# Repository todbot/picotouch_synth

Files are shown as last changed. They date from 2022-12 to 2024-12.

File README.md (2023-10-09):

# picotouch_synth

Thin captouch-based synth platform for Raspberry Pi Pico

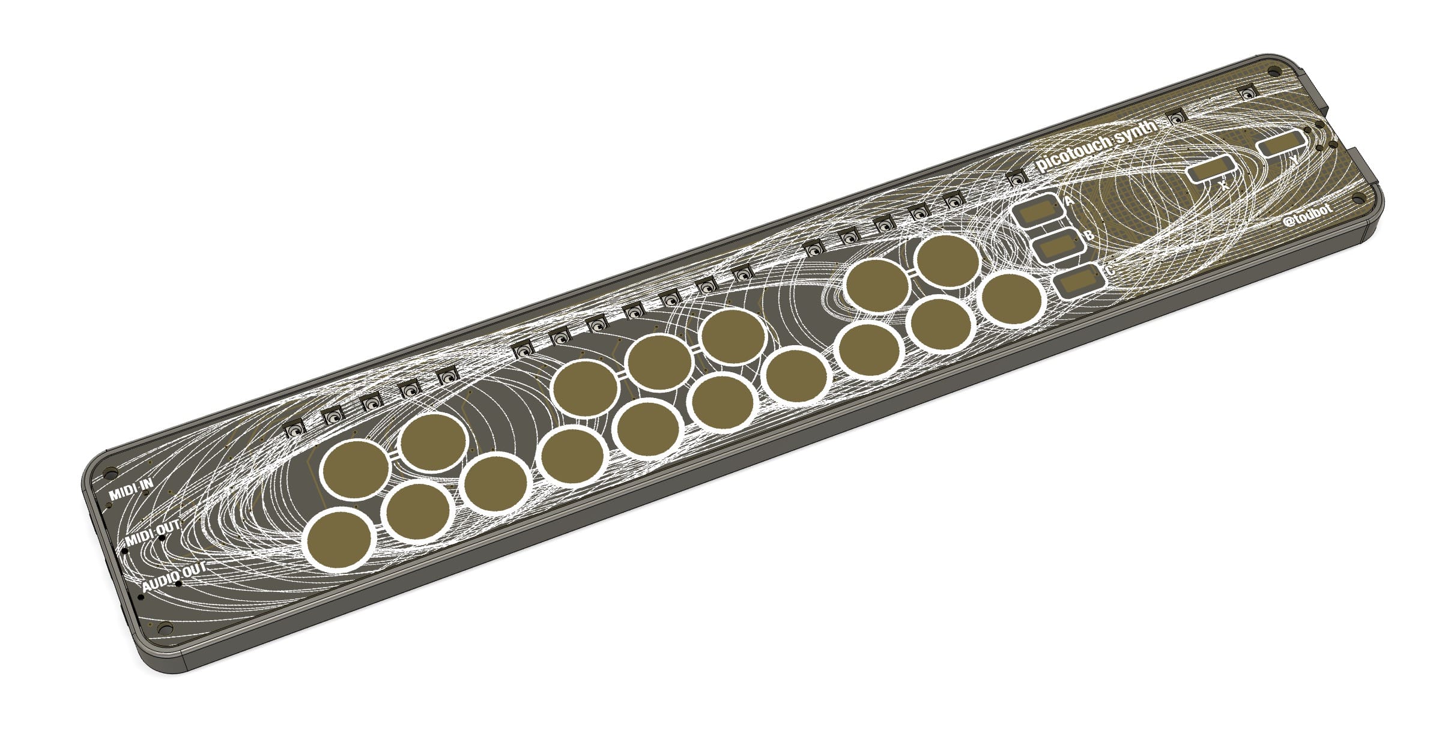
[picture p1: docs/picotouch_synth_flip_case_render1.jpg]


Features:
* Raspberry Pi Pico
* PWM Audio out
* TRS-A MIDI In / Out
* USB MIDI In/Out
* 19 RGB LEDs
* 22 touch pads (17 notes, 5 modifiers)
* Low part count: [14 BOM line items, mostly passives](./schematics/picotouch_synth_flip_bottom_bom.csv)
* Completely flat surface (only reverse-mount LEDs, capsense pads)
* 6 mm thick when in [minimal enclosure](https://github.com/todbot/picotouch_synth/tree/main/enclosure)
   (255 x 42 x 6 mm volume)

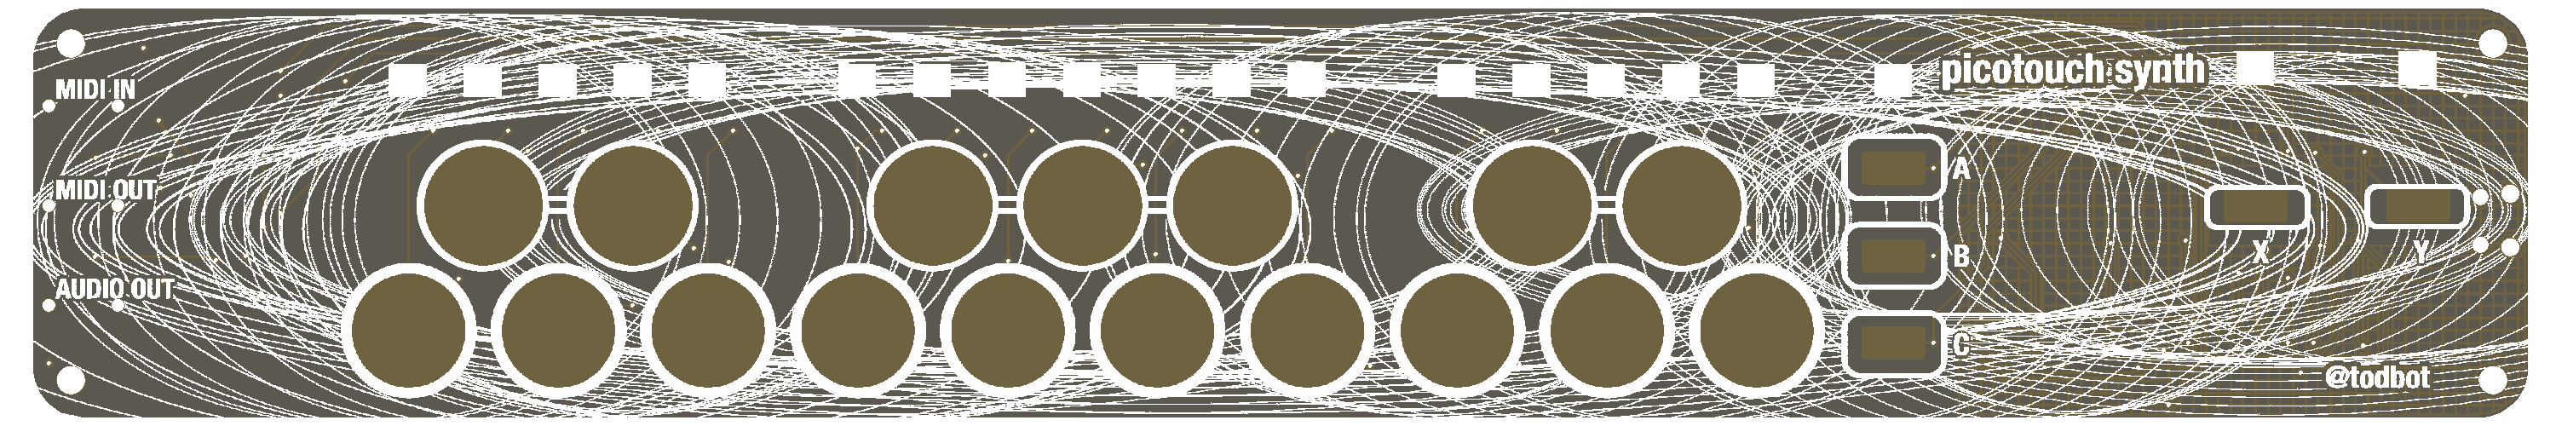
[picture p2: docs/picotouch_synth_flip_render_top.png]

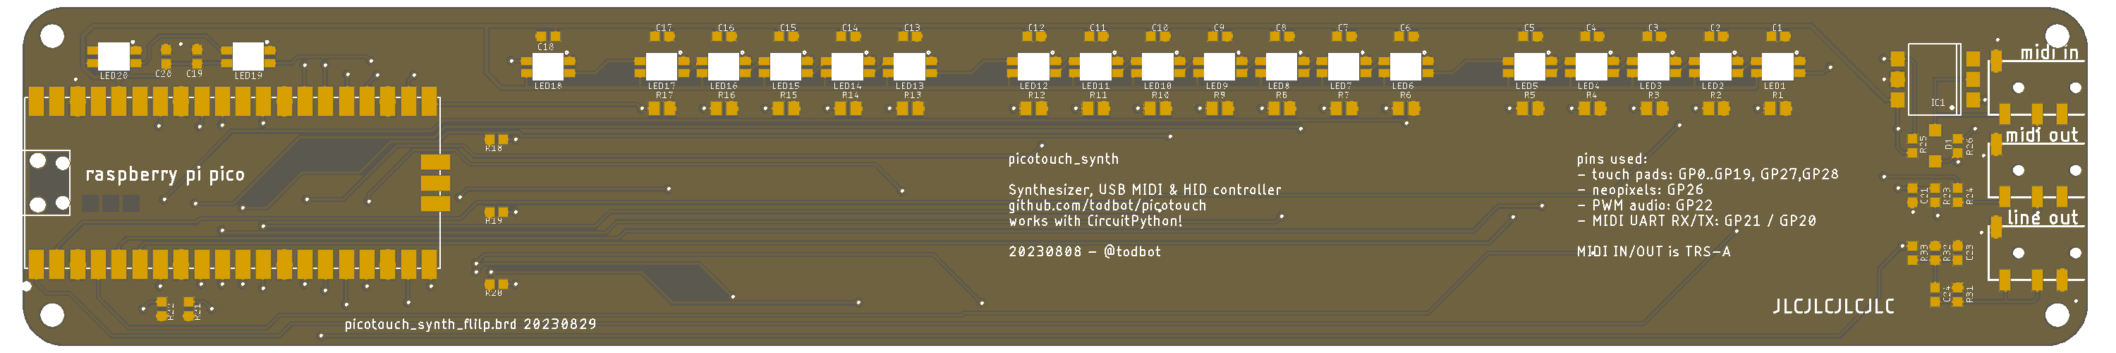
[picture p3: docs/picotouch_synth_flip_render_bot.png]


## Installing firmware

There are currently three "applications" for the picotouch_synth board, all are in active development,
so check the [Release page](https://github.com/todbot/picotouch_synth/releases)
for latest versions as prebuilt UF2 images.

- [picotouch_synth](./circuitpython/picotouch_synth) -- a wavetable synth with three different patches
  ([video demo](https://www.youtube.com/watch?v=0FgqWdkIjWM))
- [pts_drum_machine](./circuitpython/pts_drum_machine) -- a drum sample player
  ([video demo](https://www.youtube.com/watch?v=OaN6xVYXhNE))
- [hwtest](./circuitpython/hwtest/) -- simple hardware test of the board

### Installing prebuilt UF2 images

Instead of installing CircuitPython, then installling needed libraries,
and finally installing the code you want, you can just copy a UF2 file to the RPI-RP2 bootloader drive!

As a rule, all firmware will be offered as pre-built firmware UF2 images for picotouch_synth.
Go to the [Releases](https://github.com/todbot/picotouch_synth/releases) page
and download the UF2 you want.  Then, to install:

* Unplug picotouch_synth PCB board from USB
* Unclip PCB from case ([see this video on releasing the case](https://youtu.be/MjScFP873SQ))
* Hold BOOT button on Pico while plugging back into USB
* Copy the UF2 file to the RPI-RP2 drive
* When board finishes reflashing, it will reboot

__Note:__ if your Pico has more than the 2 MB standard flash
(like the [purple "RetroScaler" 16MB USB-C ones](https://www.aliexpress.us/item/3256804731684211.html)),
the UF2s will still work but the resulting CIRCUITPY drive only be 1 MB.
To get the flash space back, you will need to
[install CircuitPython](https://learn.adafruit.com/welcome-to-circuitpython/installing-circuitpython#for-rp2040-boards-3105171)
and install the code files by hand.

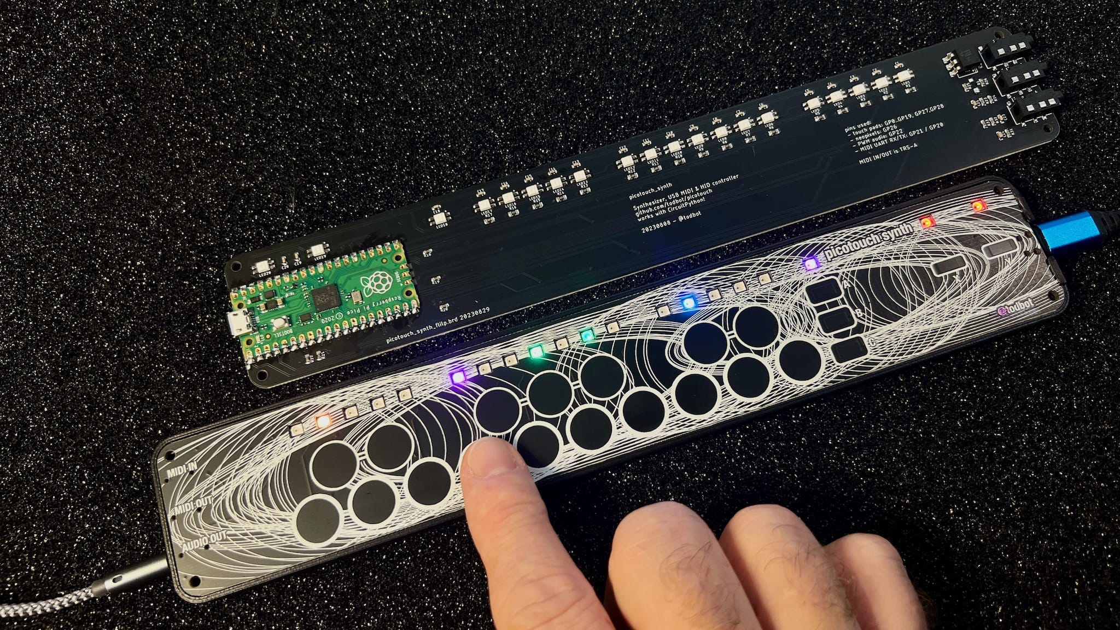
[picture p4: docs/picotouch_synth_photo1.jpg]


## Sketching in Hardware 2023 Edition

For the Sketching in Hardware conference, the firmware shipped on the boards is in
[circuitpython/picotouch_synth](https://github.com/todbot/picotouch_synth/tree/main/circuitpython/picotouch_synth)
and the pre-built UF2 firwmare in the [Releases section](https://github.com/todbot/picotouch_synth/releases/tag/v1).

There were two different boards handed out:
- [micro-USB green Raspberry Pi Picos w/ 2 MB flash](https://www.raspberrypi.com/documentation/microcontrollers/raspberry-pi-pico.html)
- [USB-C purple "RetroScaler" Pico clones w/ 16 MB flash](https://www.aliexpress.us/item/3256804731684211.html).

Both are formated as 2MB devices so if you have a purple board and want the extra flash space,
you'll need to
[install CircuitPython](https://learn.adafruit.com/welcome-to-circuitpython/installing-circuitpython#for-rp2040-boards-3105171)
and the code files by hand.

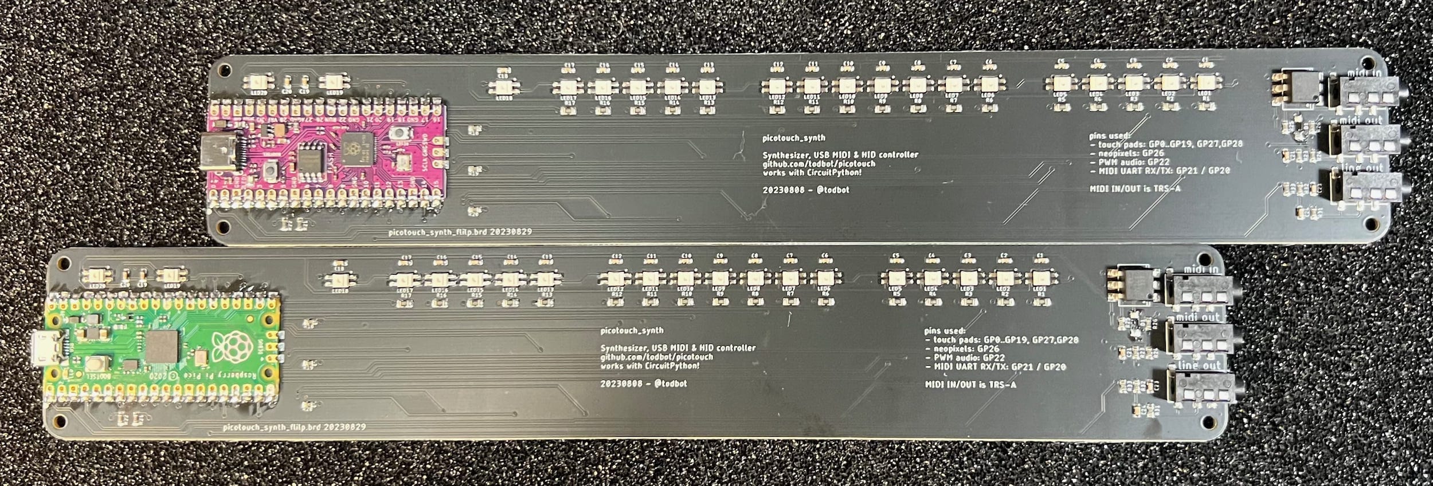
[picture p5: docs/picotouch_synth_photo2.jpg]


### The picotouch_synth application

The keyboard is laid out as top row is modulators (three groups of "sliders")
and the bottom row plays notes in a particular scale.
The A/B/C buttons select different sounds and the X/Y buttons on the right transpose up/down octaves.

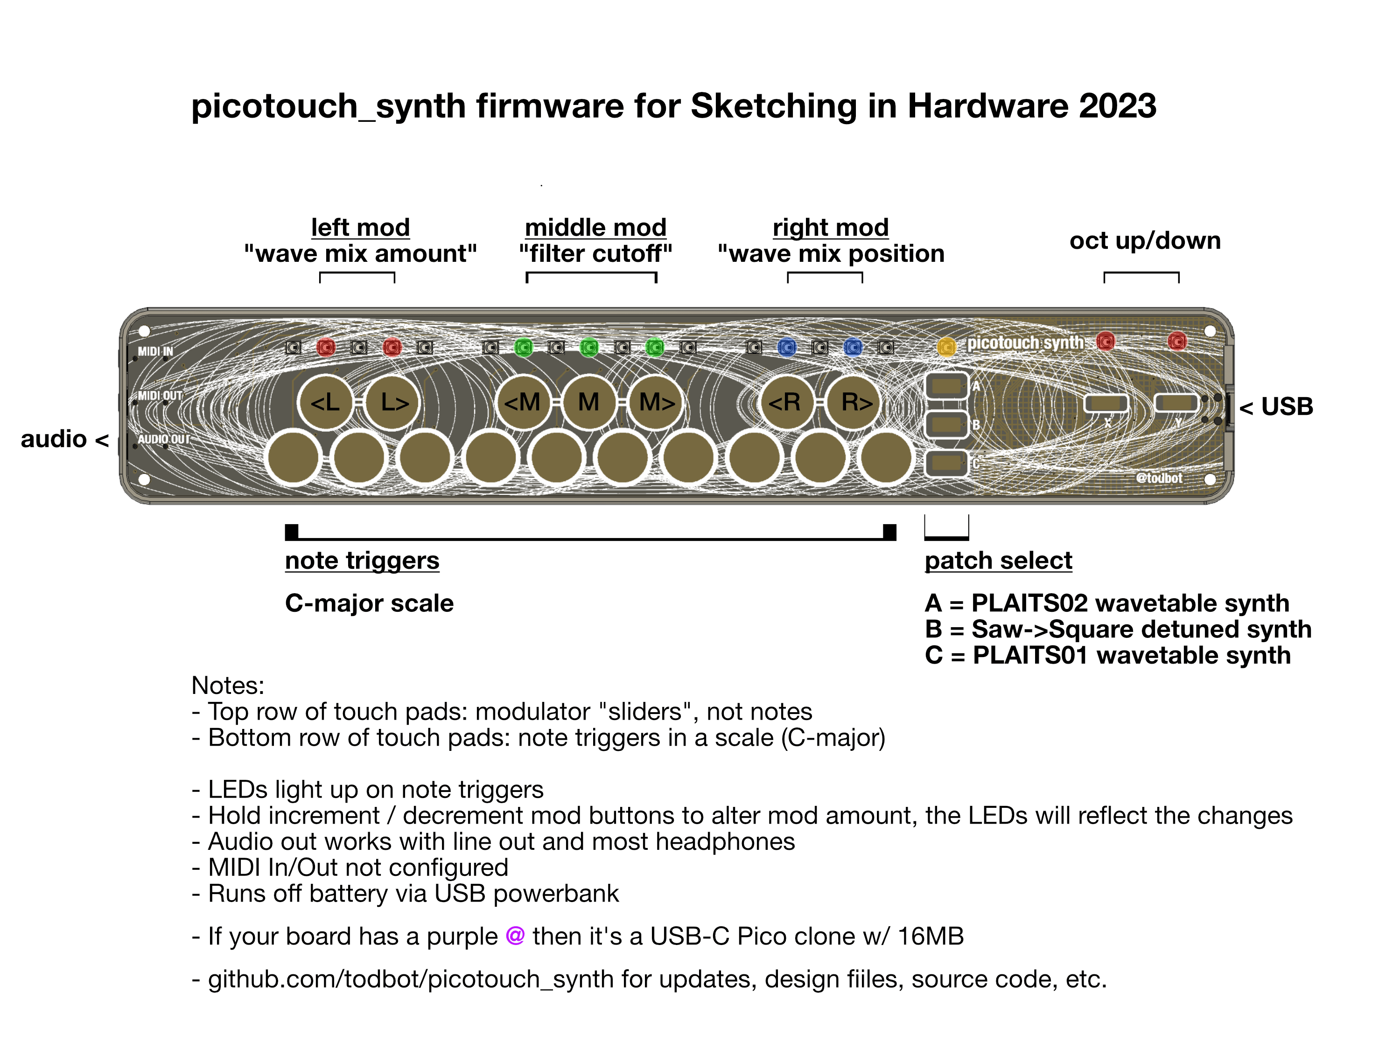
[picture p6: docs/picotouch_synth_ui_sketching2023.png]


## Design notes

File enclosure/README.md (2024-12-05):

The official minimal enclosure is "[picotouch_synth_case.stl](./picotouch_synth_case.stl)".

Fusion 360 CAD file also included.

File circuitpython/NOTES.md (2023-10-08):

# Saving UF2 images for releases

To save full state of Pico, use `picotool`
(available via homebrew on MacOS, build from source on Ubuntu)

Once picotool is installed, put board in BOOT mode by holding BOOTSEL on power up.
Then, save entire state of device into a 4MB UF2 file (twice the 2MB flash on a Pico) with:

```sh
picotool save -a picotouch_synth.uf2
```

Note that if you're using a 16MB Pico clone like the
[purple "RetroScaler" 16MB USB-C ones](https://www.aliexpress.us/item/3256804731684211.html),
the `-a` flag will generate a 32MB UF2 file.

So, to "fool" the RP2040 and CircuitPython into thinking a 16MB flash
(which is slower to write for some reason) is only a 2MB flash (and thus faster to write)
by doing a ranged save:

```sh
picotool save -r 0x10000000 0x10200000  picotouch_synth.uf2
```

This can be uploaded to a 16MB Pico clone and it will now look and act like a 2MB Pico.
The downside is you cannot access the other 14MB of the flash.

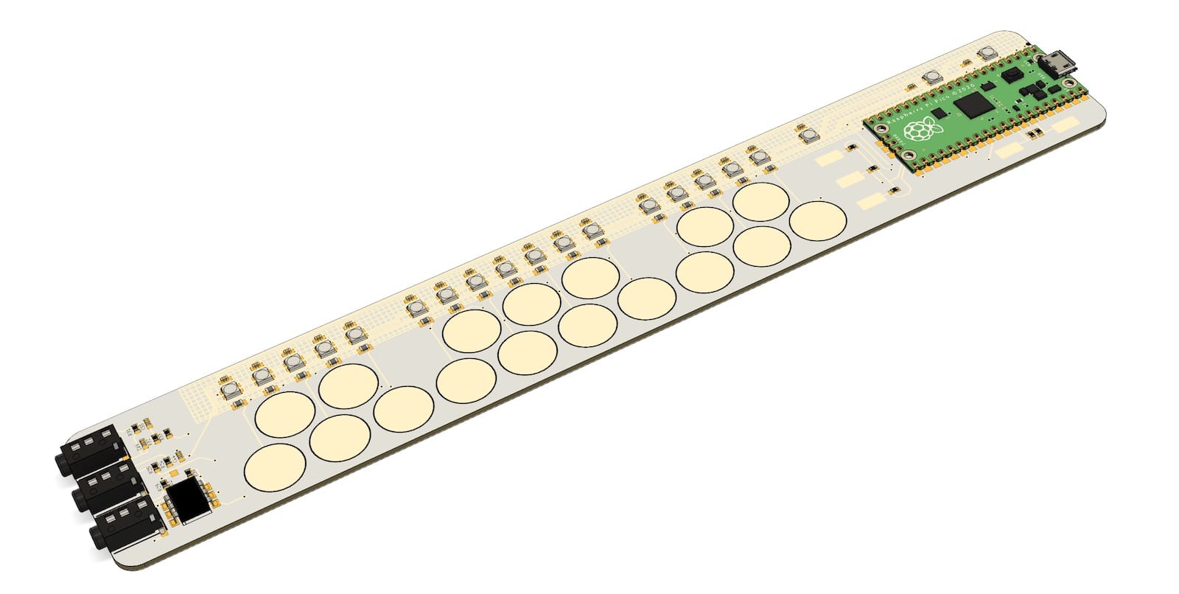
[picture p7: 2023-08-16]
docs/picotouch_synth_render1.jpg

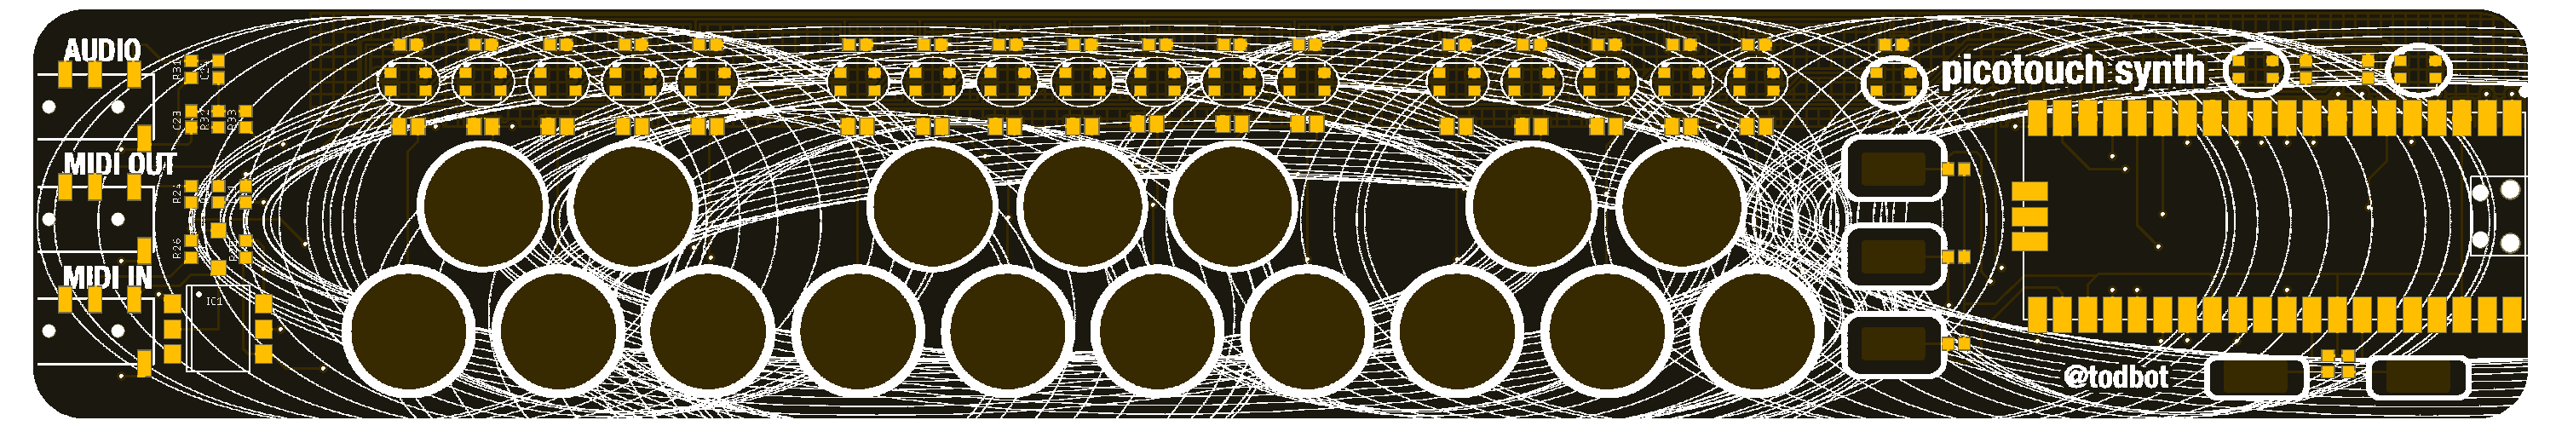
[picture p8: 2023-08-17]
docs/picotouch_synth_toprender_blk.png

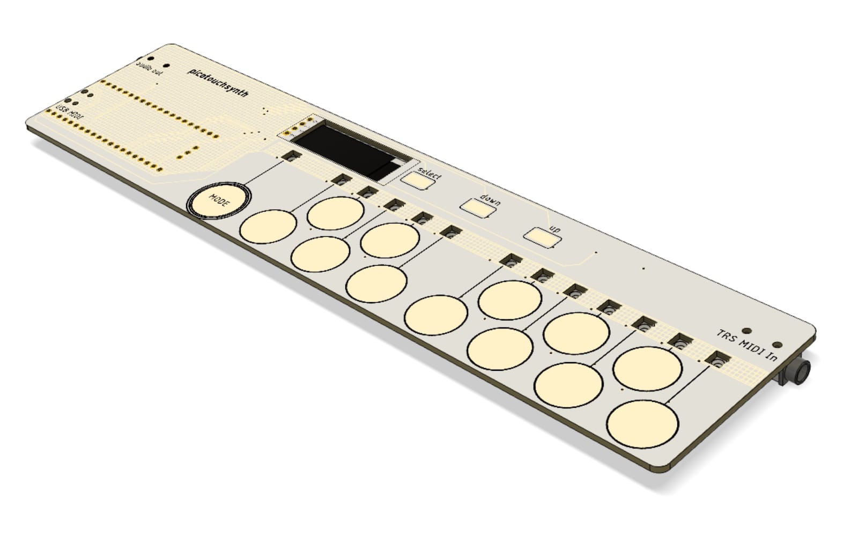
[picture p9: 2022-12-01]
docs/cadshot1.jpg

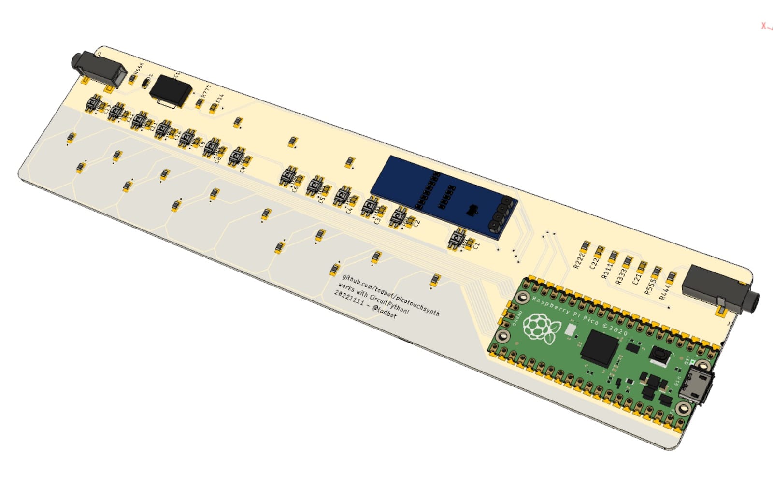
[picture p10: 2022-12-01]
docs/cadshot2.jpg

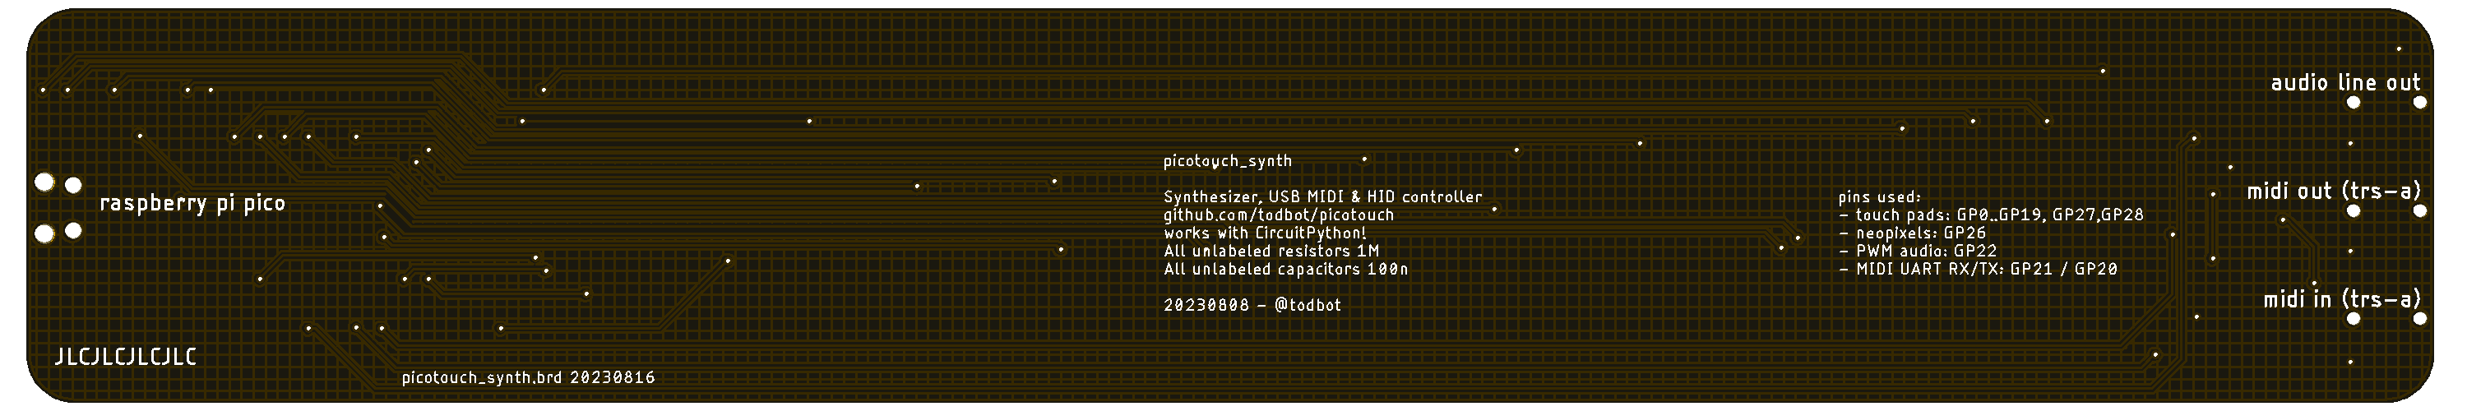
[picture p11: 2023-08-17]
docs/picotouch_synth_botrender_blk.png

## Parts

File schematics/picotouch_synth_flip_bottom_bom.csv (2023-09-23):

Comment | Designator | Footprint | LCSC Part #
1.8k | R31 | R0603
1M | R1 R2 R3 R4 R5 R6 R7 R8 R9 R10 R11 R12 R13 R14 R15 R16 R17 | R0805
1M | R18 R19 R20 R21 R22 | R0603
1N4148 | D1 | SOD123
4.70k | R25 | R0603
10 | R24 | R0603
33 | R23 | R0603
47uF | C24 | C0603
100 | R32 | R0603
100n | C1 C2 C3 C4 C5 C6 C7 C8 C9 C10 C11 C12 C13 C14 C15 C16 C17 C18 C19 C20 C21 C23 | C0603
220 | R26 R33 | R0603
AUDIO-JACK-TRRS | J1 J2 J3 | PJ-320D_SPARKFUN | C431535
H11L1MS | IC1 | DIL6-SMD | C78589
MICROBUILDER_WS2812B_SK6812E | LED1 LED2 LED3 LED4 LED5 LED6 LED7 LED8 LED9 LED10 LED11 LED12 LED13 LED14 LED15 LED16 LED17 LED18 LED19 LED20 | MICROBUILDER_NEO3535_REVERSE
RASPBERRY_PICOSMD | U1 | PICO-PKG-SMD

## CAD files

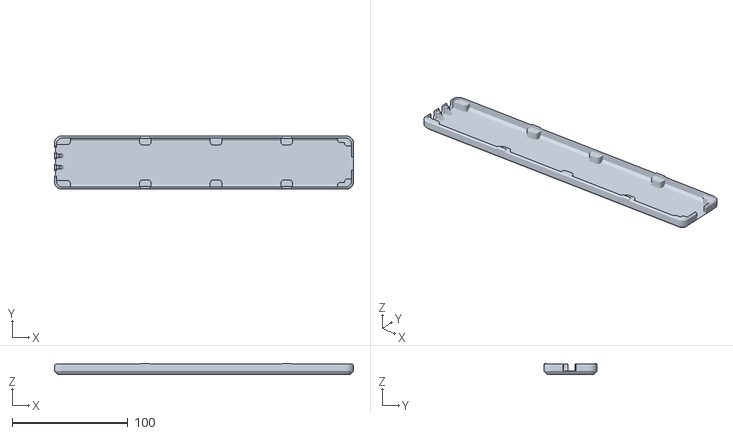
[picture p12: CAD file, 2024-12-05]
enclosure/picotouch_synth_case.stl
257.9 x 45.7 x 9.80

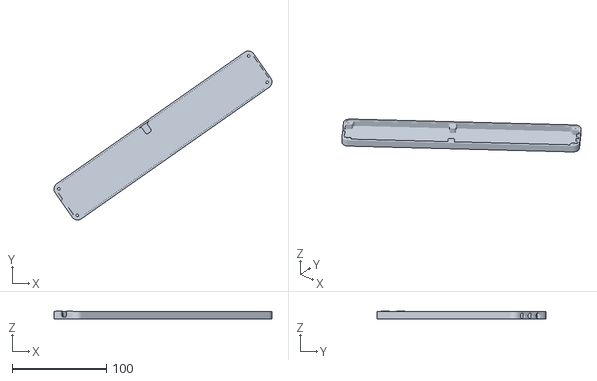
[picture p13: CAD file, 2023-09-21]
enclosure/picotouch_synth_flip_case.stl
231.8 x 179.7 x 8.90

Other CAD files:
enclosure/picotouch_synth_case.f3z
enclosure/picotouch_synth_flip_case.f3z

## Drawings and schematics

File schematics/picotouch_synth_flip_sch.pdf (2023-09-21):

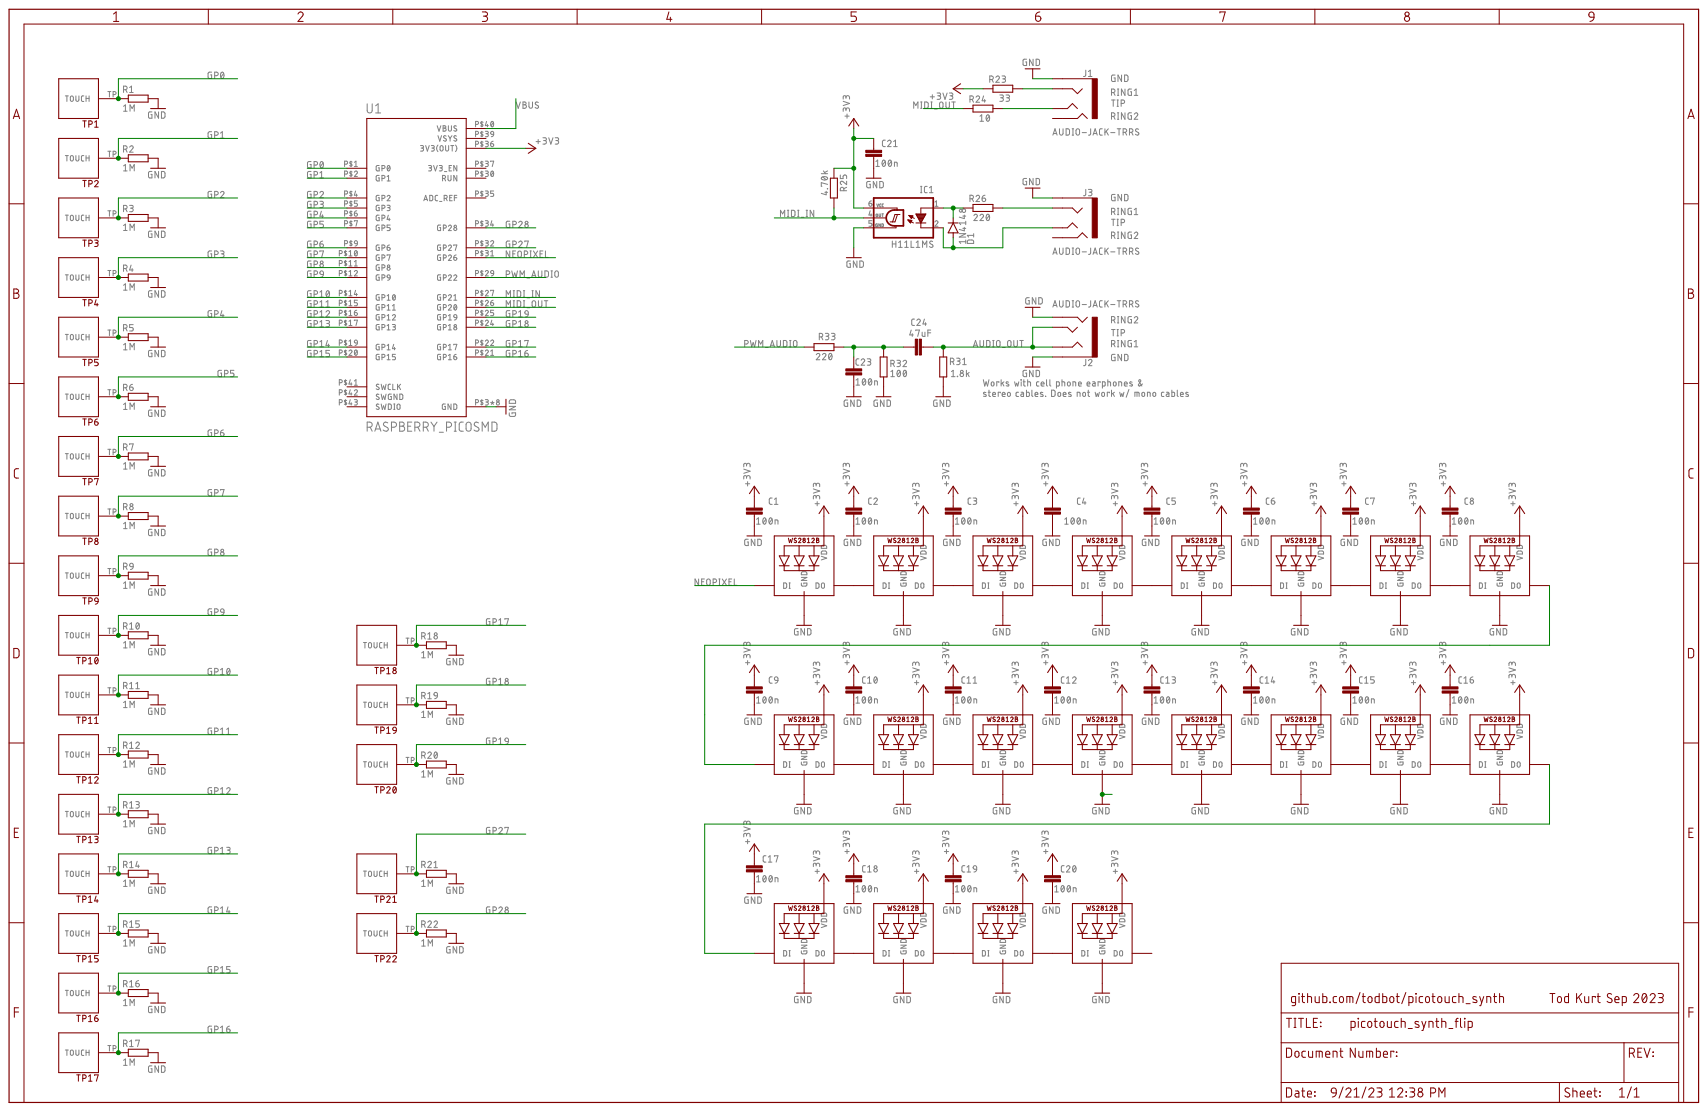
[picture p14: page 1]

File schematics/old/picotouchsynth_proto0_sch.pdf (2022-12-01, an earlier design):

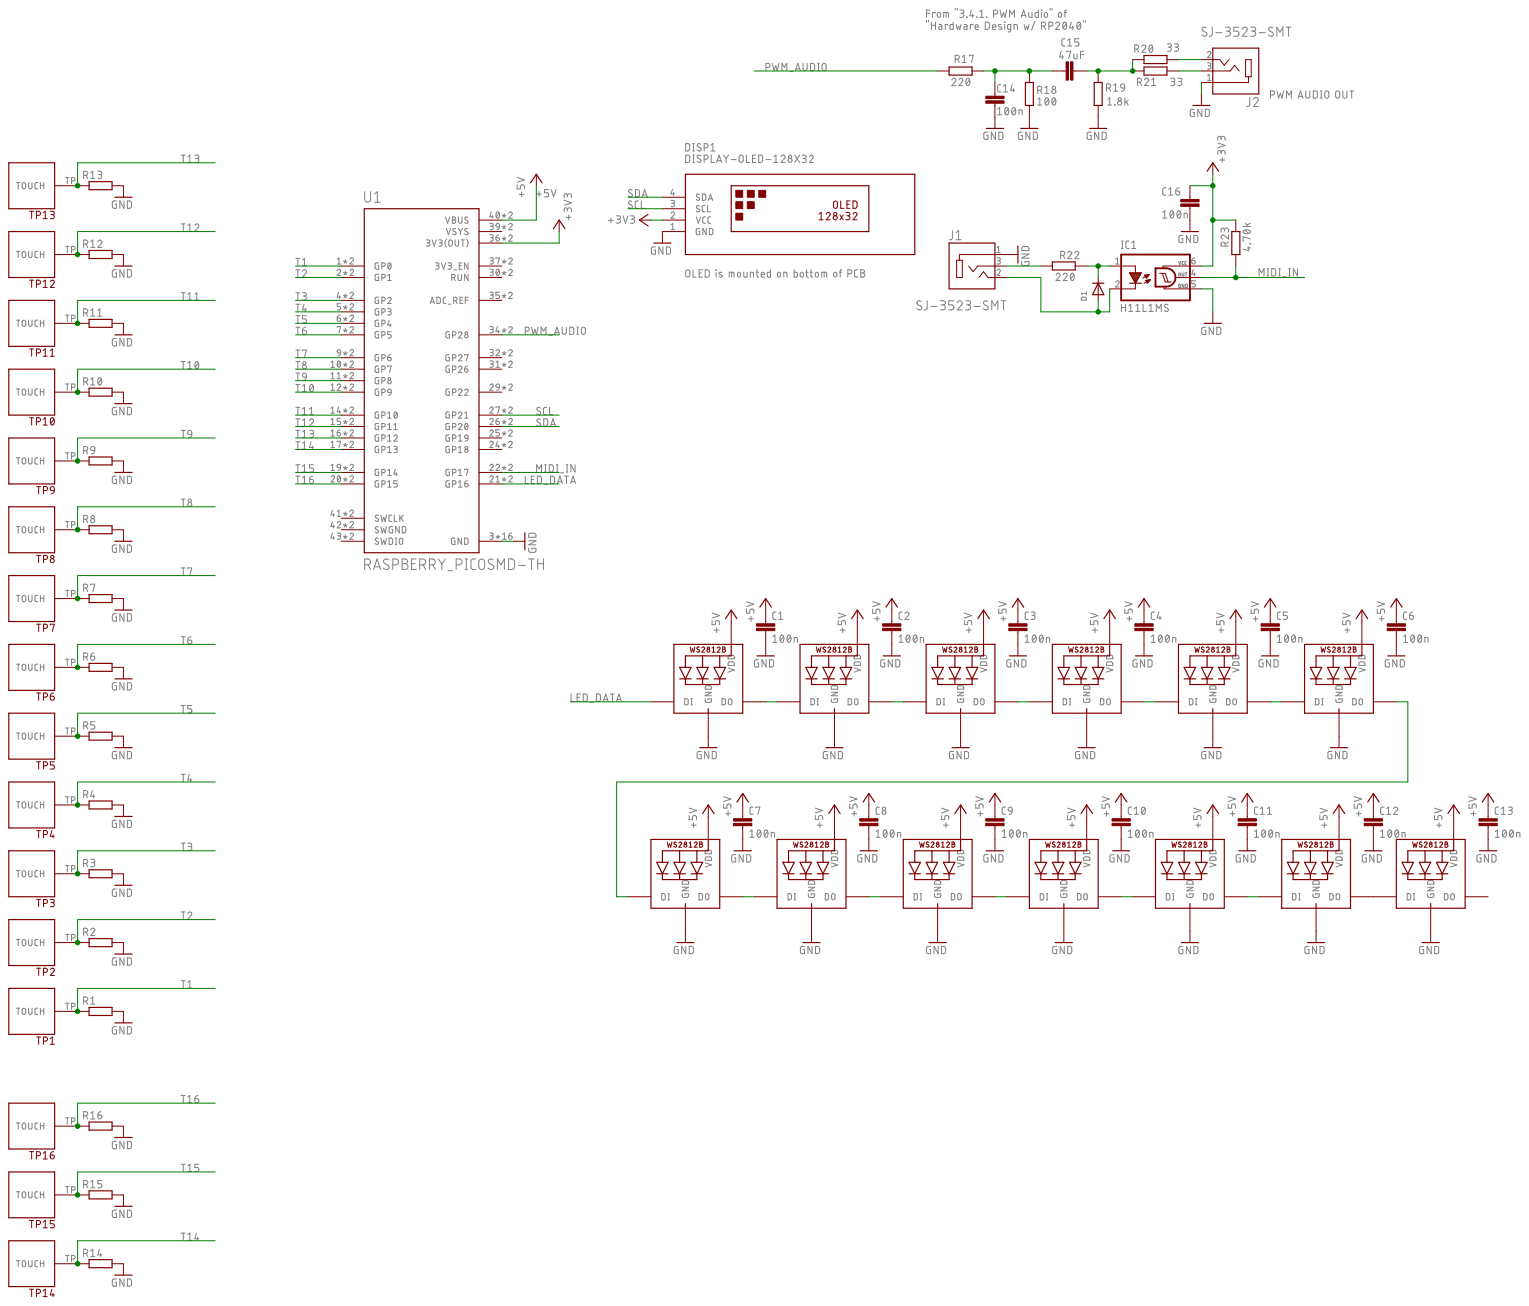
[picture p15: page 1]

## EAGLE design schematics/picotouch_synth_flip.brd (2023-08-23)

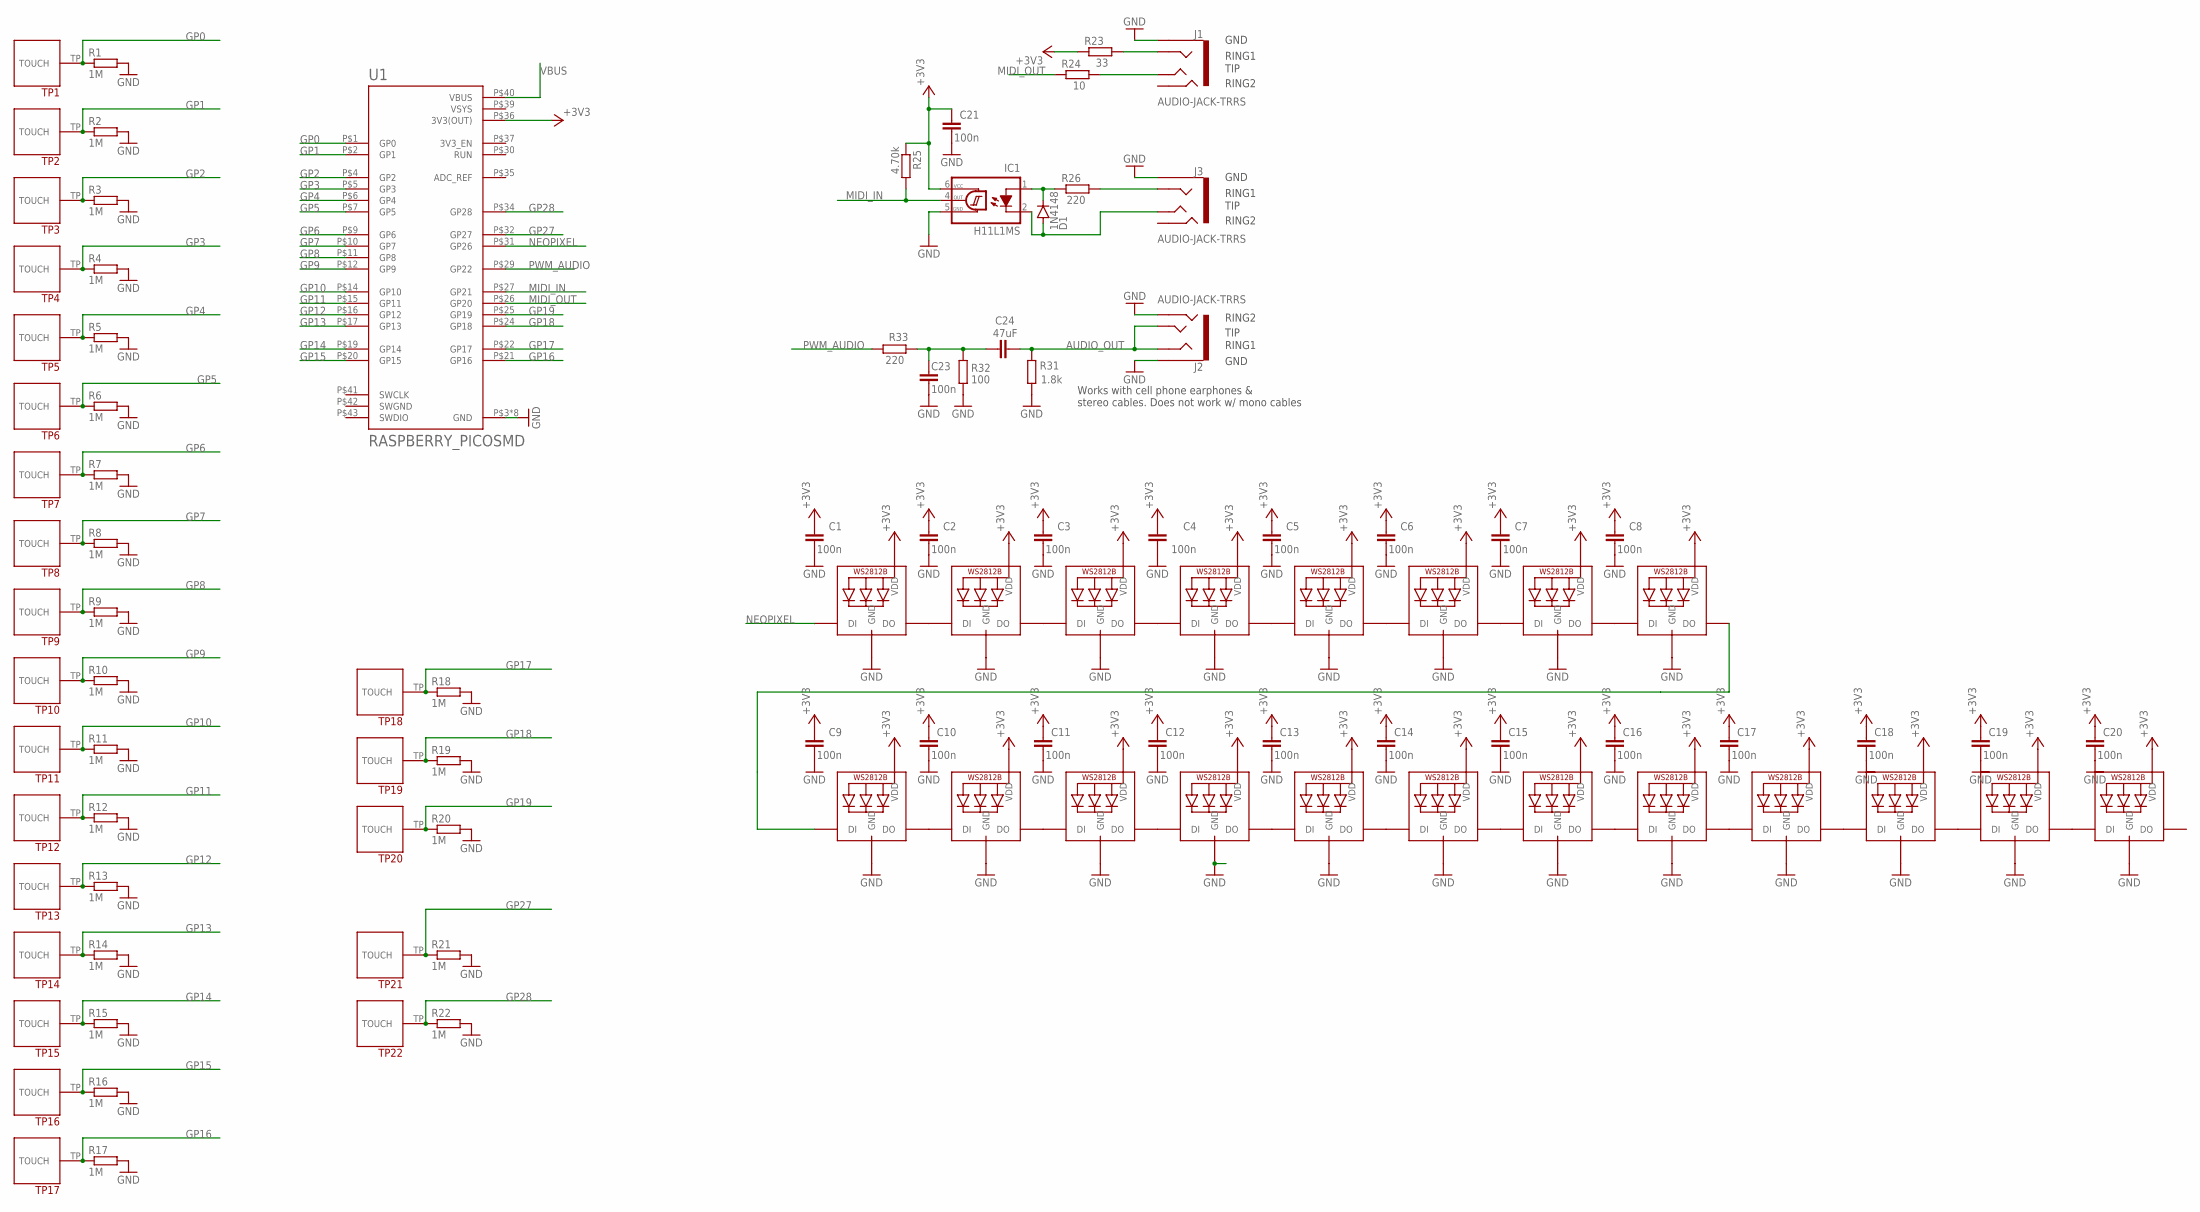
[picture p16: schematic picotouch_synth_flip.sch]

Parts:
C1, C2, C3, C4, C5, C6, C7, C8, C9, C10, C11, C12, C13, C14, C15, C16, C17, C18, C19, C20, C21, C23: 100n; C0603
C24: 47uF; C0603
D1: 1N4148; SOD123
IC1: H11L1MS; DIL6-SMD; MPN2 H11L1S; LCSC C78589
J1, J3: AUDIO-JACK-TRRS; PJ-320D_SPARKFUN
J2: AUDIO-JACK-TRRS; PJ-320D_SPARKFUN; LCSC C431535
LED1, LED2, LED3, LED4, LED5, LED6, LED7, LED8, LED9, LED10, LED11, LED12, LED13, LED14, LED15, LED16, LED17, LED18, LED19, LED20: MICROBUILDER_WS2812B_SK6812E; MICROBUILDER_NEO3535_REVERSE
R1, R2, R3, R4, R5, R6, R7, R8, R9, R10, R11, R12, R13, R14, R15, R16, R17: 1M; R0805
R18, R19, R20, R21, R22: 1M; R0603
R23: 33; R0603
R24: 10; R0603
R25: 4.70k; R0603
R26, R33: 220; R0603
R31: 1.8k; R0603
R32: 100; R0603
TP1, TP2, TP3, TP4, TP5, TP6, TP7, TP8, TP9, TP10, TP11, TP12, TP13, TP14, TP15, TP16, TP17: TOUCHPADA
TP18, TP19, TP20, TP21, TP22: TOUCHPADB
U1: RASPBERRY_PICOSMD; PICO-PKG-SMD

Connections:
+3V3: C1.1, C2.1, C3.1, C4.1, C5.1, C6.1, C7.1, C8.1, C9.1, C10.1, C11.1, C12.1, C13.1, C14.1, C15.1, C16.1, C17.1, C18.1, C19.1, C20.1, C21.1, IC1.6 (VCC), LED1.1-VDD (VDD), LED2.1-VDD (VDD), LED3.1-VDD (VDD), LED4.1-VDD (VDD), LED5.1-VDD (VDD), LED6.1-VDD (VDD), LED7.1-VDD (VDD), LED8.1-VDD (VDD), LED9.1-VDD (VDD), LED10.1-VDD (VDD), LED11.1-VDD (VDD), LED12.1-VDD (VDD), LED13.1-VDD (VDD), LED14.1-VDD (VDD), LED15.1-VDD (VDD), LED16.1-VDD (VDD), LED17.1-VDD (VDD), LED18.1-VDD (VDD), LED19.1-VDD (VDD), LED20.1-VDD (VDD), R23.1, R25.1, U1.P$36 (3V3(OUT))
AUDIO_OUT: C24.2, J2.RING1, J2.TIP, R31.1
GND: C1.2, C2.2, C3.2, C4.2, C5.2, C6.2, C7.2, C8.2, C9.2, C10.2, C11.2, C12.2, C13.2, C14.2, C15.2, C16.2, C17.2, C18.2, C19.2, C20.2, C21.2, C23.2, IC1.5 (GND), J1.EARTH, J2.EARTH, J2.RING2, J3.EARTH, LED1.3-GND (GND), LED2.3-GND (GND), LED3.3-GND (GND), LED4.3-GND (GND), LED5.3-GND (GND), LED6.3-GND (GND), LED7.3-GND (GND), LED8.3-GND (GND), LED9.3-GND (GND), LED10.3-GND (GND), LED11.3-GND (GND), LED12.3-GND (GND), LED13.3-GND (GND), LED14.3-GND (GND), LED15.3-GND (GND), LED16.3-GND (GND), LED17.3-GND (GND), LED18.3-GND (GND), LED19.3-GND (GND), LED20.3-GND (GND), R1.2, R2.2, R3.2, R4.2, R5.2, R6.2, R7.2, R8.2, R9.2, R10.2, R11.2, R12.2, R13.2, R14.2, R15.2, R16.2, R17.2, R18.2, R19.2, R20.2, R21.2, R22.2, R31.2, R32.1, U1.P$3 (GND), U1.P$8 (GND), U1.P$13 (GND), U1.P$18 (GND), U1.P$23 (GND), U1.P$28 (GND), U1.P$33 (GND), U1.P$38 (GND)
GP0: R1.1, TP1.TP, U1.P$1 (GP0)
GP1: R2.1, TP2.TP, U1.P$2 (GP1)
GP2: R3.1, TP3.TP, U1.P$4 (GP2)
GP3: R4.1, TP4.TP, U1.P$5 (GP3)
GP4: R5.1, TP5.TP, U1.P$6 (GP4)
GP5: R6.1, TP6.TP, U1.P$7 (GP5)
GP6: R7.1, TP7.TP, U1.P$9 (GP6)
GP7: R8.1, TP8.TP, U1.P$10 (GP7)
GP8: R9.1, TP9.TP, U1.P$11 (GP8)
GP9: R10.1, TP10.TP, U1.P$12 (GP9)
GP10: R11.1, TP11.TP, U1.P$14 (GP10)
GP11: R12.1, TP12.TP, U1.P$15 (GP11)
GP12: R13.1, TP13.TP, U1.P$16 (GP12)
GP13: R14.1, TP14.TP, U1.P$17 (GP13)
GP14: R15.1, TP15.TP, U1.P$19 (GP14)
GP15: R16.1, TP16.TP, U1.P$20 (GP15)
GP16: R17.1, TP17.TP, U1.P$21 (GP16)
GP17: R18.1, TP18.TP, U1.P$22 (GP17)
GP18: R19.1, TP19.TP, U1.P$24 (GP18)
GP19: R20.1, TP20.TP, U1.P$25 (GP19)
GP27: R21.1, TP21.TP, U1.P$32 (GP27)
GP28: R22.1, TP22.TP, U1.P$34 (GP28)
MIDI_IN: IC1.4 (OUT), R25.2, U1.P$27 (GP21)
MIDI_OUT: R24.1, U1.P$26 (GP20)
unnamed: D1.C, IC1.1 (A), R26.1
unnamed: J1.TIP, R24.2
unnamed: D1.A, IC1.2 (C), J3.TIP
unnamed: J3.RING1, R26.2
unnamed: C23.1, C24.1, R32.2, R33.1
unnamed: J1.RING1, R23.2
unnamed: LED1.2-DOUT (DO), LED2.4-DIN (DI)
unnamed: LED2.2-DOUT (DO), LED3.4-DIN (DI)
unnamed: LED4.2-DOUT (DO), LED5.4-DIN (DI)
unnamed: LED5.2-DOUT (DO), LED6.4-DIN (DI)
unnamed: LED6.2-DOUT (DO), LED7.4-DIN (DI)
unnamed: LED7.2-DOUT (DO), LED8.4-DIN (DI)
unnamed: LED9.2-DOUT (DO), LED10.4-DIN (DI)
unnamed: LED10.2-DOUT (DO), LED11.4-DIN (DI)
unnamed: LED12.2-DOUT (DO), LED13.4-DIN (DI)
unnamed: LED13.2-DOUT (DO), LED14.4-DIN (DI)
unnamed: LED14.2-DOUT (DO), LED15.4-DIN (DI)
unnamed: LED15.2-DOUT (DO), LED16.4-DIN (DI)
unnamed: LED3.2-DOUT (DO), LED4.4-DIN (DI)
unnamed: LED11.2-DOUT (DO), LED12.4-DIN (DI)
unnamed: LED8.2-DOUT (DO), LED9.4-DIN (DI)
unnamed: LED16.2-DOUT (DO), LED17.4-DIN (DI)
unnamed: LED17.2-DOUT (DO), LED18.4-DIN (DI)
unnamed: LED18.2-DOUT (DO), LED19.4-DIN (DI)
unnamed: LED19.2-DOUT (DO), LED20.4-DIN (DI)
NEOPIXEL: LED1.4-DIN (DI), U1.P$31 (GP26)
PWM_AUDIO: R33.2, U1.P$29 (GP22)
SWGND: U1.P$42 (SWGND)
VBUS: U1.P$40 (VBUS)
VSYS: U1.P$39 (VSYS)

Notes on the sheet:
RING2
RING1
GND
TIP
Works with cell phone earphones & stereo cables. Does not work w/ mono cables

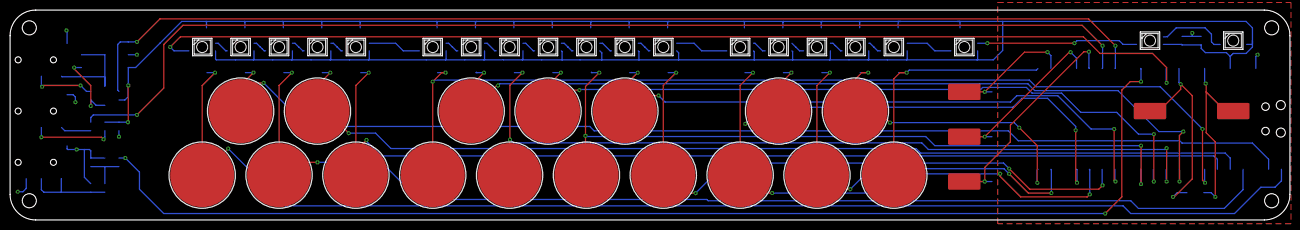
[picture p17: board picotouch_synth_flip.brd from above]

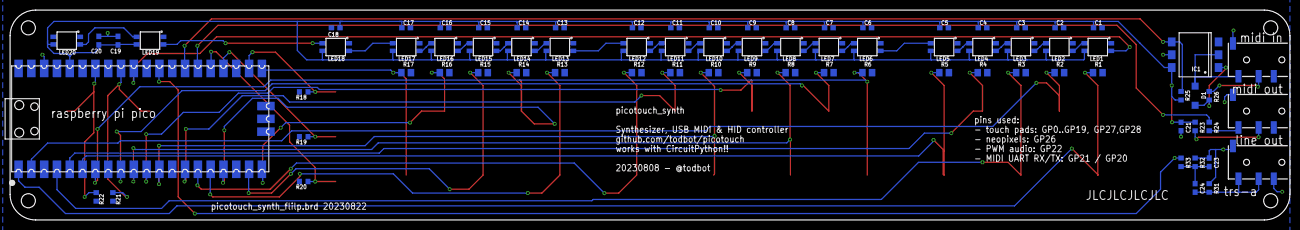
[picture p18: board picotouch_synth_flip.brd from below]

Board: 2 copper layers, 253.8 x 41.6 mm, 100 parts (58 on the bottom side), 54 nets.

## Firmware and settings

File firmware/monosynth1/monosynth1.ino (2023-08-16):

/**
 * monosynth1.ino - picotouchsynth wubwubwub synth using LowPassFilter
 * based MozziScout "mozziscout_monosynth1"
 *
 * Responds to USB MIDI too
 *
 * Libraries needed:
 * - "arduino-pico" core for Pico - https://arduino-pico.readthedocs.io/en/latest/
 * - Adafruit_TinyUSB - also select in IDE "Tools / USB Stack: Adafruit TinyUSB"
 * - Adafruit_NeoPixel
 * - Adafruit_SSD1306
 * - Mozzi - https://github.com/sensorium/Mozzi - and change Mozzi/AudioConfigRP2040.h to "AUDIO_CHANNEL_1_PIN 28"
 *
 * @todbot 1 Dec 2022
 *
 **/


// Mozzi's controller update rate, seems to have issues at 1024
// If slower than 512 can't get all MIDI from Live
#define CONTROL_RATE 512
// set DEBUG_MIDI 1 to show CCs received in Serial Monitor
#define DEBUG_MIDI_NOTE 1
#define DEBUG_MIDI_CC 1

#include <MozziGuts.h>
#include <Oscil.h>
#include <tables/triangle_analogue512_int8.h>
#include <tables/square_analogue512_int8.h>
#include <tables/saw_analogue512_int8.h>
#include <tables/cos2048_int8.h> // for filter modulation
#include <LowPassFilter.h>
#include <ADSR.h>
#include <Portamento.h>
#include <mozzi_midi.h> // for mtof()
#include <AudioDelayFeedback.h>

#include <Adafruit_TinyUSB.h>
#include <MIDI.h>
#include <Adafruit_NeoPixel.h>
#include <Wire.h>
#include <Adafruit_SSD1306.h>

#include "TouchyTouch.h"

// SETTINGS
//int portamento_time = 50;  // milliseconds
//int env_release_time = 1000; // milliseconds
byte sound_mode = 0; // patch number / program change
bool retrig_lfo = true;
int midi_base_note = 48;  // for touch keyboard
uint8_t led_fade_amount = 2;
float led_brightness = 0.15;

enum KnownCCs {
  Modulation=0,
  Resonance,
  FilterCutoff,
  PortamentoTime,
  EnvReleaseTime,
  CC_COUNT
};

// mapping of KnownCCs to MIDI CC numbers (this is somewhat standardized)
uint8_t midi_ccs[] = {
  1,   // modulation
  71,  // resonance
  74,  // filter cutoff
  5,   // portamento time
  72,  // env release time
};
uint8_t mod_vals[ CC_COUNT ];

Q16n16 deltime; // audio delay

// pinout of how picotouchsynth board is set up
const int num_touch = 16;
const int num_leds = 13;
const int display_w = 128;
const int display_h = 32;
const int touch_pins[] = { 0,1,2,3,4,5,6,7,8,9,10,11,12,13,14,15 };
const int led_pin      = 16;
const int midi_pin     = 17;
const int disp_sda_pin = 20;
const int disp_scl_pin = 21;
const int audio_pin    = 28; // edit Mozzi/AudioConfigRP2040.h to set this
// button indexes
const int BUTTON_MODE   = 0;
const int BUTTON_SELECT = 15;
const int BUTTON_UP     = 14;
const int BUTTON_DOWN   = 13;

Adafruit_USBD_MIDI usb_midi;
MIDI_CREATE_INSTANCE(Adafruit_USBD_MIDI, usb_midi, MIDIusb);

TouchyTouch touches[num_touch];
Adafruit_NeoPixel leds = Adafruit_NeoPixel(num_leds, led_pin, NEO_GRB + NEO_KHZ800);
Adafruit_SSD1306 display(128, 32, &Wire, -1); // -1 = no OLED_RESET

bool keys_pressed[12]; // one per note
int key_mode = 0;

// Oscillators
Oscil<SAW_ANALOGUE512_NUM_CELLS, AUDIO_RATE> aOsc1(SAW_ANALOGUE512_DATA);
Oscil<SAW_ANALOGUE512_NUM_CELLS, AUDIO_RATE> aOsc2(SAW_ANALOGUE512_DATA);
// Filter LFO
Oscil<COS2048_NUM_CELLS, CONTROL_RATE> kFilterMod(COS2048_DATA); // filter mod
// Amplitude envelope
//ADSR <CONTROL_RATE, AUDIO_RATE> envelope;
ADSR <CONTROL_RATE, CONTROL_RATE> envelope;

Portamento <CONTROL_RATE> portamento;
LowPassFilter lpf;

AudioDelayFeedback <128> aDel;


///////////////////////////////////////////////////////////////////////////////
// core1 is for UI and MIDI
//

// fade a color by an amount
uint32_t fadeToBlackBy(uint32_t c, uint8_t amount)
{
  uint8_t r = (uint8_t)(c >> 16);
  uint8_t g = (uint8_t)(c >>  8);
  uint8_t b = (uint8_t)c;
  // fade to black by n
  r = (r>amount) ? r - amount : 0;
  g = (g>amount) ? g - amount : 0;
  b = (b>amount) ? b - amount : 0;
  return (r << 16) | (g << 8) | b;
}

void setup1() {
  Serial.begin(115200);
  MIDIusb.begin(MIDI_CHANNEL_OMNI);   // Initiate MIDI communications, listen to all channels
  MIDIusb.turnThruOff();    // turn off echo

  // LEDs
  leds.begin();
  leds.setBrightness( led_brightness * 255 ); // 51 = 0.2
  leds.show(); // off
  /* for( int i=0; i < num_leds; i++ ) { */
  /*   uint32_t newcolor = leds.ColorHSV(i*255*20); */
  /*   leds.setPixelColor(i, newcolor); */
  /* } */
  /* leds.show(); */

  // Touch buttons
  for(int i=0; i<num_touch; i++) {
    //touches[i] = TouchyTouch();
    touches[i].begin( touch_pins[i] );
    touches[i].threshold += 200; // make a bit more noise-proof
  }

  // Display
  Wire.setSDA(disp_sda_pin);
  Wire.setSCL(disp_scl_pin);
  if(!display.begin(SSD1306_SWITCHCAPVCC, 0x3C)) { // Address 0x3D for 128x64
    Serial.println(F("SSD1306 allocation failed"));
    for(;;); // Don't proceed, loop forever
  }
  display.clearDisplay();
  display.setTextSize(2);
  display.setTextColor(WHITE);
  display.setCursor(10,0);
  display.write("pico");
  display.setCursor(60,0);
  display.write("touch");
  display.setCursor(34,17);
  display.write("synth");
  display.display();

  delay(500);

  display.dim(true);

}


void loop1() {
  handleMIDI();

  // LED fading fade all released note LEDS by same amount
  for ( int i = 0; i < 12; i++) {
    int ledi = i+1;
    uint32_t c = leds.getPixelColor(ledi);
    if( keys_pressed[i] ) {
      c = leds.ColorHSV(millis()*10, 255,255);
      //c = leds.ColorHSV(1000, 255,255);
    }
    c = fadeToBlackBy(c, led_fade_amount);
    leds.setPixelColor(ledi, c);
  }
  leds.show();

  // key handling
  for( int i=0; i<num_touch; i++) {
    touches[i].update();
    //Serial.printf("touch %d %d %d\n", i, touches[i].threshold, touches[i].raw_val_last);

    if( touches[i].rose() ) {
      Serial.printf("pressed %d\n", i);
      if( i==0 ) { // mode button
        key_mode = (key_mode + 1) % 4;
        leds.setPixelColor( 0, leds.ColorHSV(key_mode * 255 * 20, 255,255) );
        Serial.printf("key_mode:%d\n", key_mode);
      }
      else if( i > 0 && i < 13 ) { // notes
        handleNoteOn(0, midi_base_note + i - 1, 100 );
        //for(i=0;i<12;i++) { Serial.printf("%d ",keys_pressed[i]); }; Serial.println();
      }
      else if( i== 13 ) { // up
        midi_base_note += 12;
      }
      else if( i== 14 ) { // down
        midi_base_note -= 12;
      }
      else if( i== 15 ) { // select
        sound_mode = (sound_mode + 1) % 3;
        handleProgramChange(sound_mode);
      }
    }

    if( touches[i].fell() ) {
      Serial.printf("released %d\n", i);
      if( i==0 ) { // mode button
      }
      else if( i > 0 && i < 13 ) {
        handleNoteOff(0, midi_base_note + i - 1, 100 );
      }
    }
  }

  //display.display();
  delay(1); // rate limit, cand probably remove this
}

int circle_size = 6;
int keycircles_x[12];
int keycircles_y[12];

//
void handleNoteOn([[maybe_unused]] byte channel, byte note, byte velocity) {
  #if DEBUG_MIDI_NOTE
  Serial.printf("noteOn %d %d\n", note, velocity);
  #endif
  digitalWrite(LED_BUILTIN,HIGH);

  portamento.start(note);
  envelope.noteOn();

  // display
  int n = note%12;
  keys_pressed[n] = true;
  keycircles_x[n] = random(display_w);;
  keycircles_y[n] = random(display_h);;
  //display.fillCircle(keycircles_x[n], keycircles_y[n], circle_size, INVERSE);
}

//
void handleNoteOff([[maybe_unused]] byte channel, byte note, byte velocity) {
  #if DEBUG_MIDI_NOTE
  Serial.printf("noteOff %d %d\n", note, velocity);
  #endif
  digitalWrite(LED_BUILTIN,LOW);

  envelope.noteOff();

  // display
  int n = note%12;
  keys_pressed[n] = false;
  //display.fillCircle(keycircles_x[n], keycircles_y[n], circle_size, INVERSE);
}

//
void handleControlChange([[maybe_unused]] byte channel, byte cc_num, byte cc_val) {
  #if DEBUG_MIDI_CC
  Serial.printf("CC %d %d\n", cc_num, cc_val);
  #endif
  for( int i=0; i<CC_COUNT; i++) {
    if( midi_ccs[i] == cc_num ) { // we got one
      mod_vals[i] = cc_val;
      // special cases, not set every updateControl()
      if( i == PortamentoTime ) {
        portamento.setTime( mod_vals[PortamentoTime] * 2);
      }
      else if( i == EnvReleaseTime ) {
        Serial.printf("release time: %d\n", mod_vals[EnvReleaseTime]*10);
        envelope.setReleaseTime( mod_vals[EnvReleaseTime]*10 );
      }
    }
  }
}

//
void handleProgramChange(byte m) {
  Serial.print("program change:"); Serial.println((byte)m);
  sound_mode = m;
  if( sound_mode == 0 ) {
    aOsc1.setTable(SAW_ANALOGUE512_DATA);
    aOsc2.setTable(SAW_ANALOGUE512_DATA);

    mod_vals[Modulation] = 0;   // FIXME: modulation unused currently
    mod_vals[Resonance] = 93;
    mod_vals[FilterCutoff] = 60;
    mod_vals[PortamentoTime] = 50; // actually in milliseconds
    mod_vals[EnvReleaseTime] = 50; // in 10x milliseconds (100 = 1000 msecs)

    lpf.setCutoffFreqAndResonance(mod_vals[FilterCutoff], mod_vals[Resonance]*2);

    kFilterMod.setFreq(4.0f);  // fast
    envelope.setADLevels(255, 255);
    envelope.setTimes(50, 200, 20000, mod_vals[EnvReleaseTime]*10 );
    portamento.setTime( mod_vals[PortamentoTime] );
  }
  else if ( sound_mode == 1 ) {
    aOsc1.setTable(SQUARE_ANALOGUE512_DATA);
    aOsc2.setTable(SQUARE_ANALOGUE512_DATA);

    mod_vals[Resonance] = 50;
    mod_vals[EnvReleaseTime] = 15;

    lpf.setCutoffFreqAndResonance(mod_vals[FilterCutoff], mod_vals[Resonance]*2);

    kFilterMod.setFreq(0.5f);     // slow
    envelope.setADLevels(255, 255);
    envelope.setTimes(50, 100, 20000, (uint16_t)mod_vals[EnvReleaseTime]*10 );
    portamento.setTime( mod_vals[PortamentoTime] );
  }
  else if ( sound_mode == 2 ) {
    aOsc1.setTable(TRIANGLE_ANALOGUE512_DATA);
    aOsc2.setTable(TRIANGLE_ANALOGUE512_DATA);
    mod_vals[FilterCutoff] = 65;
    //kFilterMod.setFreq(0.25f);    // slower
    //retrig_lfo = false;
  }
}

//
void handleMIDI() {
  while( MIDIusb.read() ) {  // use while() to read all pending MIDI, shouldn't hang
    switch(MIDIusb.getType()) {
      case midi::ProgramChange:
        handleProgramChange(MIDIusb.getData1());
        break;
      case midi::ControlChange:
        handleControlChange(0, MIDIusb.getData1(), MIDIusb.getData2());
        break;
      case midi::NoteOn:
        handleNoteOn( 0, MIDIusb.getData1(),MIDIusb.getData2());
        break;
      case midi::NoteOff:
        handleNoteOff( 0, MIDIusb.getData1(),MIDIusb.getData2());
        break;
      default:
        break;
    }
  }
}

///////////////////////////////////////////////////////////////////////////////
// core0 is for audio synthesis
//

//
void setup() {
  pinMode(LED_BUILTIN, OUTPUT);

  startMozzi(CONTROL_RATE);

  envelope.setReleaseLevel(0);

  aDel.setFeedbackLevel(-20); // can be -128 to 127

  handleProgramChange(0); // set our initial patch
}

//
void loop() {
  audioHook();
}

byte envgain;  // do envelope in updateControl() instead of in updateAudio()

// mozzi function, called at CONTROL_RATE times per second
void updateControl() {
  //handleMIDI();

  // map the lpf modulation into the filter range (0-255), corresponds with 0-8191Hz, kFilterMod runs -128-127
  //uint8_t cutoff_freq = cutoff + (mod_amount * (kFilterMod.next()/2));
  //  uint16_t fm = ((kFilterMod.next() * mod_vals[Modulation]) / 128) + 127 ;
  //  uint8_t cutoff_freq = constrain(mod_vals[FilterCutoff] + fm, 0,255 );

  //  lpf.setCutoffFreqAndResonance(cutoff_freq, mod_vals[Resonance]*2);

  lpf.setCutoffFreqAndResonance(mod_vals[FilterCutoff], mod_vals[Resonance]*2);  // don't *2 filter since we want 0-4096Hz

  envelope.update();
  envgain = envelope.next(); // this is where it's different to an audio rate envelope

  Q16n16 pf = portamento.next();  // Q16n16 is a fixed-point fraction in 32-bits (16bits . 16bits)
  aOsc1.setFreq_Q16n16(pf);
  aOsc2.setFreq_Q16n16(pf*1.015);

  deltime = Q8n0_to_Q16n16(17); //  + ((long)kDelSamps.next()<<12);
}

// mozzi function, called at AUDIO_RATE times per second
AudioOutput_t updateAudio() {
  long asig = lpf.next( aOsc1.next() + aOsc2.next() );
  asig = envgain * asig; // 16-bits: 8 signal bits + 8 envelope bits
  //aDel.next(asig, deltime)
  return MonoOutput::fromAlmostNBit(18, asig );
  //return MonoOutput::fromAlmostNBit(18, 0); // test noise
  //return MonoOutput::fromAlmostNBit(18, (asig>>3) + aDel.next(asig, deltime) );
  //return MonoOutput::fromAlmostNBit(18, envgain * asig); // 16 = 8 signal bits + 8 envelope bits
}

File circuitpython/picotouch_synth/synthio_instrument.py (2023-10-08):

# synthio_instrumnt.py -- synth abstractions for synthio
# 1 Sep 2023 - @todbot / Tod Kurt
# Part of https://github.com/todbot/picotouch_synth

import time
import synthio
from collections import namedtuple
from micropython import const
import ulab.numpy as np
try:
    import adafruit_wave
except:
    print("synthio_instrment: no WAV import available")

# mix between values a and b, works with numpy arrays too,  t ranges 0-1
def lerp(a, b, t):  return (1-t)*a + t*b

# like arduino map()
def map_range(s, a1, a2, b1, b2):  return  b1 + ((s - a1) * (b2 - b1) / (a2 - a1))


class Waves:
    """
    Generate waveforms for either oscillator or LFO use
    """
    def make_waveform(waveid, size=512, volume=30000):
        waveid = waveid.upper()
        if waveid=='SIN' or waveid=='SINE':
            return Waves.sine(size,volume)
        elif waveid=='SQU' or waveid=='SQUARE':
            return Waves.square(size,volume)
        elif waveid=='SAW':
            return Waves.saw(size,volume)
        elif waveid=='TRI' or waveid == 'TRIANGLE':
            return Waves.triangle(size, -volume, volume)
        elif waveid=='SIL' or waveid=='SILENCE':
            return Waves.silence(size)
        elif waveid=='NZE' or waveid=='NOISE':
            return Waves.noise(size,volume)
        else:
            print("unknown wave type", waveid)

    def sine(size, volume):
        return np.array(np.sin(np.linspace(0, 2*np.pi, size, endpoint=False)) * volume, dtype=np.int16)

    def square(size, volume):
        return np.concatenate((np.ones(size//2, dtype=np.int16) * volume,
                               np.ones(size//2, dtype=np.int16) * -volume))

    def triangle(size, min_vol, max_vol):
        return np.concatenate((np.linspace(min_vol, max_vol, num=size//2, dtype=np.int16),
                               np.linspace(max_vol, min_vol, num=size//2, dtype=np.int16)))

    def saw(size, volume):
        return Waves.saw_down(size,volume)

    def saw_down(size, volume):
        return np.linspace(volume, -volume, num=size, dtype=np.int16)

    def saw_up(size, volume):
        return np.linspace(-volume, volume, num=size, dtype=np.int16)

    def silence(size):
        return np.zeros(size, dtype=np.int16)

    def noise(size,volume):
        # tbd
        pass

    def from_list( vals ):
        print("Waves.from_list: vals=",vals)
        return np.array( [int(v) for v in vals], dtype=np.int16 )

    def lfo_ramp_up_pos():
        return np.array( (0,32767), dtype=np.int16)

    def lfo_ramp_down_pos():
        return np.array( (32767,0), dtype=np.int16)

    def lfo_triangle_pos():
        return np.array( (0, 32767, 0), dtype=np.int16)

    def lfo_triangle():
        return np.array( (0, 32767, 0, -32767), dtype=np.int16)

    def wav(filepath, size=256, pos=0):
        with adafruit_wave.open(filepath) as w:
            if w.getsampwidth() != 2 or w.getnchannels() != 1:
                raise ValueError("unsupported format")
            #n = w.getnframes() if size==0 else size
            n = size
            w.setpos(pos)
            return np.frombuffer(w.readframes(n), dtype=np.int16)

    def wav_info(filepath):
        with adafruit_wave.open(filepath) as w:
            return (w.getnframes(), w.getnchannels(), w.getsampwidth())


class Wavetable:
    """
    A 'waveform' for synthio.Note that uses a wavetable with a scannable
    wave position. A wavetable is a collection of harmonically-related
    single-cycle waveforms. Often the waveforms are 256 samples long and
    the wavetable containing 64 waves. The wavetable oscillator lets the
    user pick which of those 64 waves to use, usually allowing one to mix
    between two waves.

    Some example wavetables usable by this classs: https://waveeditonline.com/

    In this implementation, you select a wave position (wave_pos) that can be
    fractional, and the fractional part allows for mixing of the waves
    at wave_pos and wave_pos+1.
    """

    def __init__(self, filepath, size=256, in_memory=False):
        self.filepath = filepath
        """Sample size of each wave in the table"""
        self.size = size
        self.w = adafruit_wave.open(filepath)
        print("hi wavetable", filepath)
        if self.w.getsampwidth() != 2 or self.w.getnchannels() != 1:
            raise ValueError("unsupported WAV format")
        self.wav = None
        if in_memory:  # load entire WAV into RAM
            self.wav = np.frombuffer(self.w.readframes(self.w.getnframes()), dtype=np.int16)
        self.samp_posA = -1

        """How many waves in this wavetable"""
        self.num_waves = self.w.getnframes() / self.size
        """ The waveform to be used by synthio.Note """
        self.waveform = Waves.silence(size) # makes a buffer for us to lerp into
        self.set_wave_pos(0)

    def set_wave_pos(self,wave_pos):
        """
        wave_pos integer part of specifies which wave from 0-num_waves,
        and fractional part specifies mix between wave and wave next to it
        (e.g. wave_pos=15.66 chooses 1/3 of waveform 15 and 2/3 of waveform 16)
        """
        wave_pos = min(max(wave_pos, 0), self.num_waves-1)  # constrain
        self.wave_pos = wave_pos

        samp_posA = int(wave_pos) * self.size
        samp_posB = int(wave_pos+1) * self.size
        #print("samp_posA", samp_posA, self.samp_posA, wave_pos)
        if samp_posA != self.samp_posA:  # avoid needless computation
            if self.wav:  # if we've loaded the entire wavetable into RAM
                waveformA = self.wav[samp_posA : samp_posA + self.size] # slice
                waveformB = self.wav[samp_posB : samp_posB + self.size]
            else:
                self.w.setpos(samp_posA)
                waveformA = np.frombuffer(self.w.readframes(self.size), dtype=np.int16)
                self.w.setpos(samp_posB)
                waveformB = np.frombuffer(self.w.readframes(self.size), dtype=np.int16)

            self.samp_posA = samp_posA  # save
            self.waveformA = waveformA
            self.waveformB = waveformB

        # fractional position between a wave A & B
        wave_pos_frac = wave_pos - int(wave_pos)
        # mix waveforms A & B and copy result into waveform used by synthio
        self.waveform[:] = lerp(self.waveformA, self.waveformB, wave_pos_frac)

    def deinit(self):
        self.w.close()


class LFOParams:
    """
    """
    def __init__(self, rate=None, scale=None, offset=None, once=False, waveform=None):
        self.rate = rate
        self.scale = scale
        self.offset = offset
        self.once = once
        self.waveform = waveform

    def make_lfo(self):
        return synthio.LFO(rate=self.rate, once=self.once,
                           scale=self.scale, offset=self.offset,
                           waveform=self.waveform)
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

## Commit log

2022-12-01 picotouchsynth now has its own repo
    [picotouchsynth.sch]
2022-12-01 add led test to hw test
2022-12-04 now captouch buttons work as keyboard
2022-12-04 now with LEDs
2022-12-04 now with fading LEDs
2023-08-16 moved from picotouch repo
    [picotouch_synth.sch, picotouchsynth.sch, picotouchsynth_proto0.sch]
2023-08-16 commit before fab
    [picotouch_synth.sch]
2023-08-17 update README with PCB renders
2023-08-17 moved topsilk to tNames so it renders
    [picotouch_synth.sch]
2023-08-22 forgot to wire 3v3. wow I am really dumb
    [picotouch_synth.sch]
2023-08-23 flip version
    [picotouch_synth_flip.brd, picotouch_synth_flip.sch]
2023-08-23 flip version updates
    [picotouch_synth_flip.brd]
2023-08-30 fix silkscreen jack labels
2023-09-21 case checkin, "v29" in fusion
    [picotouch_synth_flip_case.f3z, picotouch_synth_flip_case.stl]
2023-09-21 pdf of sch
    [picotouch_synth_flip.sch]
2023-09-23 add bom and cpl
    [picotouch_synth_flip_bottom_bom.csv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]
2023-10-08 add midi in/out, add better scales, fix octave pad bug
    [code.py, synthio_instrument.py]
2023-10-08 first cut at drum machine
2023-10-08 fix patch setup for patchC, and use PLAITS03 instead
    [code.py]
2023-10-08 pts_drum_machine fixes, still just a sample player
    [code.py]
2023-10-08 update docs about different sketching board types
2023-10-08 small video on how to release the PCB from the case
2023-10-10 cleanup sch directory
    [picotouch_synth.sch]
2023-10-11 change to DIY debouncing: full keyscan goes from 25 millis to 9 milllis
2024-12-05 add new easier to use case
    [picotouch_synth_case.f3z]
